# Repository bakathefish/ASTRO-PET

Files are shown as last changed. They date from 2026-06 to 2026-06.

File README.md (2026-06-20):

ZINE

# AstroPet

## What is it?
 
AstroPet is a small desk pet built for astrophotographers. It consists of two boards: a sensor unit that you leave outside exposed to the sky which reads actual sky conditions in real time, and a display unit that sits on your desk with a cute little animated pet face on a round screen.
 
The pet's mood tells you whether it's worth going outside to shoot tonight. A happy face means go, a sad face means stay in. No internet, no weather app, no phone needed so its ideal for when you're at a dark site in the middle of nowhere and just want a quick answer before dragging all your gear out into the cold.

## Why did i make it?

Everytime i want to go outside and shoot theres always the laziness preventing me. im always thinking what if its too bright, what if theres too many clouds, is the humidity right, is it time to go shoot yet or do i wait more. by the time iv figured it out all the motivation to shoot has faded, or the time to shoot has. so i figured if i have a small device pet telling me exactly what to do and if its a good idea to shoot, without me ever leaving the comfort of my bed, its perfect. i wanted something that would work anywhere regardless of if i had wifi.

right now im only doing the most basic things with the sensors, however overtime i plan to improve a lot on the design and firmware since this is just a v1 build of it. overtime i plan on adding more moods, maybe optional wifi modes that also pull planetary data and moon phase, and perhaps tell you what to shoot or an ideal setup to use. iv already ordered both pcbs and all the parts for them, so the plan now is to build them, test them properly irl and keep developing them out from there.

## how does it work

the two boards talk to eachother wirelessly over the esp32s esp now protocol, a direct device to device protocol that needs no router, no hotspot, or internet connection.

**board one** the sensor unit, it sits outside reading the data, the sensors fire every 5 seconds and the data is then transmitted over to board 2.
**board two** the display unit, it sits on your desk, receives the packets, runs three checks on the data and outputs a face to match all of it.

both boards just run off usb c for now since this is a v1.

## Why the ir temperature finds clouds
a clear sky would be a direct line of sight to space which would be cold, and the mlx90614 pointed upward would read that cold radiation and return a very very low temperature. however if it was pointed at a cloud the temperature would be much higher, and when we compare this with the surrounding temperature taken by the other sensor it allows us to predict if clouds are blocking the sky or not, without using any internet forecast data or camera since those will be unreliable in the dark.

## PCB 1 - Sensor Unit Schematic

SCH_sensor module_1-P1_2026-06-20

## PCB 1 - Sensor Unit Board


## PCB 2 - Display Unit Schematic


## PCB 2 - Display Unit Board


## 3d models / cases

the `3d models/` folder has the printable cases for both units, the desk display unit and the outdoor sensor unit. theres no screws anywhere in this whole build, both cases have clips on the inside that the pcb snaps into, and the lids clip shut over the top.

### display unit (indoor)

the round window is for the screen. you slide the pcb into the slot inside and it snaps into the clips, then the lid clips on over it.

<p align="center">
  display case front<br>
  <b>front</b>
</p>

<p align="center">
  display case back<br>
  <b>back</b>
</p>

<p align="center">
  display case view
</p>

### sensor unit (outdoor)

same setup, the pcb snaps into the clips inside and the lid clips closed over it. to actually put it outside you can just 3m double tape the bottom of the case onto a wall, a ledge or your roof, wherever it can see the open sky, so theres no drilling or screws needed for mounting it either.

<p align="center">
  sensor case front<br>
  <b>front</b>
</p>

<p align="center">
  sensor case back<br>
  <b>back</b>
</p>

## the firmware

the firmware is two little arduino sketches, `sensor_unit.ino` for the outside board and `display_unit.ino` for the desk board. i kept it super simple on purpose, theres barely any code so its easy to read and beginner friendly if you wanna build your own or mess around with it.

the sensor board just reads the three sensors and broadcasts them over esp now every 5 seconds. the display board listens, runs the three checks, and draws a happy or sad face. if it stops hearing from the sensor for a bit the pet goes to sleep so you know the link dropped.

right now theres **no gps and no moon phase** in the code, its the bare minimum to get the core thing working and keep it easy to flash. im adding gps + moon phase (and maybe an optional wifi mode) in a **v2** once iv built and tested the boards irl. the gps connector is already on the board so its just a firmware update later.

### flashing it
to flash, open the sketch in arduino ide, install the **esp32 by Espressif** board package and pick **ESP32S3 Dev Module** as the board, then plug the board in over usb c, select its com port and hit upload. install the libraries for whichever board youre flashing first:
- sensor board libraries: `Adafruit TSL2591`, `Adafruit MLX90614`, `Adafruit BME280`
- display board library: `TFT_eSPI`
- the round display needs `TFT_eSPI` set up for the **GC9A01** driver in its `User_Setup.h`, if the screen is black or garbled thats almost always why

## assembly

first step is getting the boards made, head to `PCB_FILES/` and download both gerber zips (`ASTROPET_SENSOR_PCB.zip` and `ASTROPET_DISPLAY_PCB.zip`), get them made at jlcpcb, and order the parts from the BOM below.

once the boards arrive, populate them by hand using the silkscreen markers as a guide. start with the smallest parts first like the resistors and caps, then move up to the bigger stuff like the esp32 modules and the connectors. everything on here is hand solderable so you dont need anything fancy, just a normal iron and a bit of flux.

after both boards are soldered, flash the firmware onto them. grab `sensor_unit.ino` and `display_unit.ino` from the `firmware/` folder and flash each one to its own board using the steps in the firmware section above. power for both is just usb c, so plug each board in over usb c to flash it and to run it.

then the cases, and remember theres no screws anywhere in this build.

for the display unit, connect the round screen to the board first and power it over usb c to check it actually works. once it does, unplug it, slide the pcb into the slot inside the case so it snaps into the clips, plug the screen back in, then clip the lid shut. thats it.

for the sensor unit its the same thing, the pcb snaps into the clips inside the case and the lid clips closed over it. to put it outside just 3m double tape the bottom of the case onto a wall, ledge or roof where it can see the sky.

once both are closed up, power them over usb c, keep the display unit on your desk and stick the sensor unit outside facing up at the open sky, and the pet should start reacting to whats going on up there.

## BOM

full bom with lcsc part numbers is in `BOM.csv`. order the pcbs from jlcpcb using the gerber files in `PCB_FILES/`.
 
| Qty | Description | Manufacturer | MPN | Supplier | Part No. | Unit (USD) | Total (USD) |
|-----|---|---|-----|---|---|---|---|
| 2 | [ESP32-S3-MINI-1-N4R2 module](https://www.lcsc.com/product-detail/C3013941.html?s_z=n_q_C3013941&globalKeyword=C3013941) | Espressif | ESP32-S3-MINI-1-N4R2 | LCSC | C3013941 | $5.15 | $10.31 |
| 2 | [RES 4.3kΩ 0603](https://www.lcsc.com/product-detail/C2930099.html?s_z=n_q_C2930099&globalKeyword=C2930099) | FOJAN | FRC0603F4301TS | LCSC | C2930099 | $0.002 | $0.003 |
| 7 | [CAP 100nF 0603](https://www.lcsc.com/product-detail/C14663.html?s_z=n_q_C14663&globalKeyword=C14663) | YAGEO | CC0603KRX7R9BB104 | LCSC | C14663 | $0.03 | $0.18 |
| 4 | [CAP 47µF 0805](https://www.lcsc.com/product-detail/C6119904.html?s_z=n_q_C6119904&globalKeyword=C6119904) | HRE | CGA0805X5R476M100MT | LCSC | C6119904 | $0.13 | $0.53 |
| 6 | [RES 10kΩ 0603](https://www.lcsc.com/product-detail/C2930027.html?s_z=n_q_C2930027&globalKeyword=C2930027) | FOJAN | FRC0603J103TS | LCSC | C2930027 | $0.001 | $0.008 |
| 4 | [Tactile button](https://www.lcsc.com/product-detail/C720477.html?s_z=n_q_C720477&globalKeyword=C720477) | XUNPU | TS-1088-AR02016 | LCSC | C720477 | $0.054 | $0.22 |
| 1 | [GPS connector JST 4-pin](https://www.lcsc.com/product-detail/C131334.html?s_z=n_q_C131334&globalKeyword=C131334) | JST | B4B-PH-K-S(LF)(SN) | LCSC | C131334 | $0.047 | $0.047 |
| 1 | [BME280 temp/humidity/pressure](https://www.lcsc.com/product-detail/C92489.html?s_z=n_q_C92489&globalKeyword=C92489) | Bosch | BME280 | LCSC | C92489 | $6.37 | $6.37 |
| 1 | [MLX90614ESF-BAA IR cloud sensor](https://www.lcsc.com/product-detail/C490604.html?s_z=n_q_C490604&globalKeyword=C490604) | Melexis | MLX90614ESF-BAA-000-TU | LCSC | C490604 | $6.56 | $6.56 |
| 1 | [TSL25911FN sky brightness sensor](https://www.lcsc.com/product-detail/C176812.html?s_z=n_q_C176812&globalKeyword=C176812) | AMS | TSL25911FN | LCSC | C176812 | $3.22 | $3.22 |
| 2 | [LED indicator](https://www.lcsc.com/product-detail/C5354976.html?s_z=n_q_C5354976&globalKeyword=C5354976) | Kingbright | APHHS1005LSECK/J3-PF | LCSC | C5354976 | $0.49 | $0.97 |
| 2 | [CAP 22µF](https://www.lcsc.com/product-detail/C5674.html?s_z=n_q_C5674&globalKeyword=C5674) | Samsung | CL21A226MQQNNNE | LCSC | C5674 | $0.039 | $0.078 |
| 2 | [LDO 3.3V AP2112K](https://www.lcsc.com/product-detail/C51118.html?s_z=n_q_C51118&globalKeyword=C51118) | Diodes Inc. | AP2112K-3.3TRG1 | LCSC | C51118 | $0.163 | $0.327 |
| 2 | [CAP 10µF](https://www.lcsc.com/product-detail/C15850.html?s_z=n_q_C15850&globalKeyword=C15850) | Samsung | CL21A106KAYNNNE | LCSC | C15850 | $0.048 | $0.095 |
| 4 | [RES 22Ω 0603](https://www.lcsc.com/product-detail/C23345.html?s_z=n_q_C23345&globalKeyword=C23345) | UNI-ROYAL | 0603WAF220JT5E | LCSC | C23345 | $0.002 | $0.006 |
| 2 | [ESD diode USBLC6-2SC6](https://www.lcsc.com/product-detail/C7519.html?s_z=n_q_C7519&globalKeyword=C7519) | ST | USBLC6-2SC6 | LCSC | C7519 | $0.154 | $0.308 |
| 2 | [Schottky diode MBR0520](https://www.lcsc.com/product-detail/C5204745.html?s_z=n_q_C5204745&globalKeyword=C5204745) | TWGMC | MBR0520 | LCSC | C5204745 | $0.021 | $0.042 |
| 2 | [Ferrite bead BLM18PG121SN1D](https://www.lcsc.com/product-detail/C14709.html?s_z=n_q_C14709&globalKeyword=C14709) | muRata | BLM18PG121SN1D | LCSC | C14709 | $0.017 | $0.034 |
| 2 | [PTC resettable fuse 75mA](https://www.lcsc.com/product-detail/C2830242.html?s_z=n_q_C2830242&globalKeyword=C2830242) | Jinrui | JK-nSMD075/6V | LCSC | C2830242 | $0.039 | $0.077 |
| 4 | [RES 5.1kΩ 0603](https://www.lcsc.com/product-detail/C2907044.html?s_z=n_q_C2907044&globalKeyword=C2907044) | FOJAN | FRC0603F5101TS | LCSC | C2907044 | $0.002 | $0.006 |
| 1 | [Display header 1x7 2.54mm](https://www.lcsc.com/product-detail/C22438157.html?s_z=n_q_C22438157&globalKeyword=C22438157) | Hanxia | HX PM2.54-1x7P ZC-Y | LCSC | C22438157 | $0.12 | $0.12 |
| 1 | [NEO-6M GPS module](https://robu.in/product/neo-6m-gps-module-with-eprom-normal-quality/) * | — | — | Robu.in | 1270231 | $3.00 | $3.00 |
| 1 | [GC9A01 1.28" round IPS display](https://robu.in/product/goldenmorning-gc9a01-7p-240x240-spi-1-28-inch-round-display-module/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) | — | — | Robu.in | R123209 | $4.00 | $4.00 |
| 2 | [2-layer PCB](https://cart.jlcpcb.com/quote?spm=jlcpcb.Public.2006) | — | — | JLCPCB | — | $2.10 | $4.20 |

**Total: ~$40.50 USD**

\* the neo-6m gps isnt used by the v1 firmware, its only on the board so gps + moon phase can be added later as a firmware update (see the firmware section). you can leave it unpopulated for now if you want.

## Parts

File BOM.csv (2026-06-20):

No. | Qty | Description | Manufacturer | MPN | Supplier | Part No. | Link | Unit (USD) | Total (USD) | Notes
1 | 2 | ESP32-S3-MINI-1-N4R2 module | Espressif | ESP32-S3-MINI-1-N4R2 | LCSC | C3013941 | https://www.lcsc.com/product-detail/C3013941.html?s_z=n_q_C3013941&globalKeyword=C3013941 | 5.15 | 10.31
2 | 2 | RES 4.3kΩ 0603 | FOJAN | FRC0603F4301TS | LCSC | C2930099 | https://www.lcsc.com/product-detail/C2930099.html?s_z=n_q_C2930099&globalKeyword=C2930099 | 0.002 | 0.003
3 | 7 | CAP 100nF 0603 | YAGEO | CC0603KRX7R9BB104 | LCSC | C14663 | https://www.lcsc.com/product-detail/C14663.html?s_z=n_q_C14663&globalKeyword=C14663 | 0.03 | 0.18
4 | 4 | CAP 47µF 0805 | HRE | CGA0805X5R476M100MT | LCSC | C6119904 | https://www.lcsc.com/product-detail/C6119904.html?s_z=n_q_C6119904&globalKeyword=C6119904 | 0.13 | 0.53
5 | 6 | RES 10kΩ 0603 | FOJAN | FRC0603J103TS | LCSC | C2930027 | https://www.lcsc.com/product-detail/C2930027.html?s_z=n_q_C2930027&globalKeyword=C2930027 | 0.001 | 0.008
6 | 4 | Tactile button | XUNPU | TS-1088-AR02016 | LCSC | C720477 | https://www.lcsc.com/product-detail/C720477.html?s_z=n_q_C720477&globalKeyword=C720477 | 0.054 | 0.22
7 | 1 | GPS connector JST 4-pin | JST | B4B-PH-K-S(LF)(SN) | LCSC | C131334 | https://www.lcsc.com/product-detail/C131334.html?s_z=n_q_C131334&globalKeyword=C131334 | 0.047 | 0.047
8 | 1 | BME280 temp/humidity/pressure | Bosch | BME280 | LCSC | C92489 | https://www.lcsc.com/product-detail/C92489.html?s_z=n_q_C92489&globalKeyword=C92489 | 6.37 | 6.37
9 | 1 | MLX90614ESF-BAA IR cloud sensor | Melexis | MLX90614ESF-BAA-000-TU | LCSC | C490604 | https://www.lcsc.com/product-detail/C490604.html?s_z=n_q_C490604&globalKeyword=C490604 | 6.56 | 6.56
10 | 1 | TSL25911FN sky brightness sensor | AMS | TSL25911FN | LCSC | C176812 | https://www.lcsc.com/product-detail/C176812.html?s_z=n_q_C176812&globalKeyword=C176812 | 3.22 | 3.22
11 | 2 | LED indicator | Kingbright | APHHS1005LSECK/J3-PF | LCSC | C5354976 | https://www.lcsc.com/product-detail/C5354976.html?s_z=n_q_C5354976&globalKeyword=C5354976 | 0.49 | 0.97
12 | 2 | CAP 22µF | Samsung | CL21A226MQQNNNE | LCSC | C5674 | https://www.lcsc.com/product-detail/C5674.html?s_z=n_q_C5674&globalKeyword=C5674 | 0.039 | 0.078
13 | 2 | LDO 3.3V AP2112K | Diodes Inc. | AP2112K-3.3TRG1 | LCSC | C51118 | https://www.lcsc.com/product-detail/C51118.html?s_z=n_q_C51118&globalKeyword=C51118 | 0.163 | 0.327
14 | 2 | CAP 10µF | Samsung | CL21A106KAYNNNE | LCSC | C15850 | https://www.lcsc.com/product-detail/C15850.html?s_z=n_q_C15850&globalKeyword=C15850 | 0.048 | 0.095
15 | 4 | RES 22Ω 0603 | UNI-ROYAL | 0603WAF220JT5E | LCSC | C23345 | https://www.lcsc.com/product-detail/C23345.html?s_z=n_q_C23345&globalKeyword=C23345 | 0.002 | 0.006
16 | 2 | ESD diode USBLC6-2SC6 | ST | USBLC6-2SC6 | LCSC | C7519 | https://www.lcsc.com/product-detail/C7519.html?s_z=n_q_C7519&globalKeyword=C7519 | 0.154 | 0.308
17 | 2 | Schottky diode MBR0520 | TWGMC | MBR0520 | LCSC | C5204745 | https://www.lcsc.com/product-detail/C5204745.html?s_z=n_q_C5204745&globalKeyword=C5204745 | 0.021 | 0.042
18 | 2 | Ferrite bead BLM18PG121SN1D | muRata | BLM18PG121SN1D | LCSC | C14709 | https://www.lcsc.com/product-detail/C14709.html?s_z=n_q_C14709&globalKeyword=C14709 | 0.017 | 0.034
19 | 2 | PTC resettable fuse 75mA | Jinrui | JK-nSMD075/6V | LCSC | C2830242 | https://www.lcsc.com/product-detail/C2830242.html?s_z=n_q_C2830242&globalKeyword=C2830242 | 0.039 | 0.077
20 | 4 | RES 5.1kΩ 0603 | FOJAN | FRC0603F5101TS | LCSC | C2907044 | https://www.lcsc.com/product-detail/C2907044.html?s_z=n_q_C2907044&globalKeyword=C2907044 | 0.002 | 0.006
21 | 1 | Display header 1x7 2.54mm | Hanxia | HX PM2.54-1x7P ZC-Y | LCSC | C22438157 | https://www.lcsc.com/product-detail/C22438157.html?s_z=n_q_C22438157&globalKeyword=C22438157 | 0.12 | 0.12
22 | 1 | NEO-6M GPS module |  |  | Robu.in | 1270231 | https://robu.in/product/neo-6m-gps-module-with-eprom-normal-quality/ | 3 | 3 | not used by v1 firmware, optional, can leave unpopulated
23 | 1 | GC9A01 1.28" round IPS display |  |  | Robu.in | R123209 | https://robu.in/product/goldenmorning-gc9a01-7p-240x240-spi-1-28-inch-round-display-module/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 | 4 | 4
24 | 2 | 2-layer PCB |  |  | JLCPCB |  | https://cart.jlcpcb.com/quote?spm=jlcpcb.Public.2006 | 2.1 | 4.2
 |  |  |  |  |  |  |  | TOTAL (USD) | 40.71

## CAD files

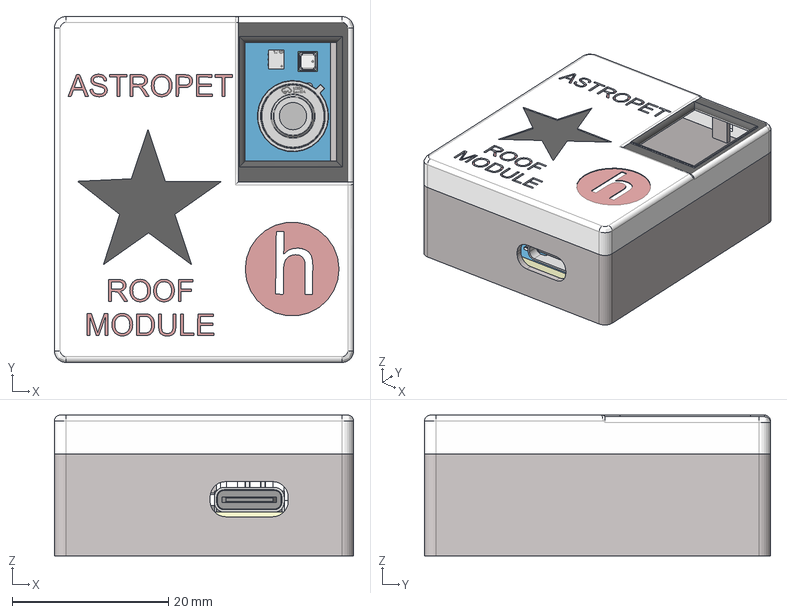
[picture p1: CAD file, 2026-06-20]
3d models/ASTROPET_ROOF.step
38.3 x 44.3 x 18.0 mm
Board~mEyu
SW-SMD_L3.9-W3.0-P4.45~SW-SMD_L3.9-W2.9-H2.0-LS4.8~L6eX x 2
C0805~C0805_L2.0-W1.3-H1.3~uovY x 4
C0603~C0603_L1.6-W0.8-H0.8~0AP0 x 5
TO-39-4_MELEXIS_MLX90614XXA~TO-39-4_MELEXIS_MLX90614XXA~DdZP
F1206~F1206_L3.2-W1.7-H0.6~eitb
L0603~L0603_L1.6-W0.8-H0.5_BEAD~ujBa
SOT-23-6_L2.9-W1.6-P0.95-LS2.8-BL~SOT-23-6_L2.9-W1.6-H1.5-LS2.8-P0.95 ~Gd1i
LED0402-RD_RED~LED0402-RD_RED~1LAU
R0603~R0603~h1d3 x 9
SOD-123_L2.7-W1.6-LS3.7-RD-A~SOD-123_L2.7-W1.6-LS3.7-RD-A~o5sd
BULETM-SMD_ESP32-S3-MINI-1-N8~BULETM-SMD_ESP32-S3-MINI-1-N8~e1Fh
USB-C-SMD_TYPEC-304J-BCP16~USB-C-SMD_TYPEC-304J-BCP16~HAKh
SOT-25-5_L2.9-W1.6-P0.95-LS2.8-BL~SOT-25-5_L2.9-W1.6-P0.95-LS2.8-BL~4 HVq
LGA-8_BME280_BL~LGA-8_L2.5-W2.5-H0.9-P0.65~OiZE
DFN-6_L2.4-W2.0-P0.65-BL~DFN-6_L2.4-W2.0-P0.65-BL~LcKs
CONN-TH_B4B-PH-K-S~PH2.0-LI-4P~i7Em

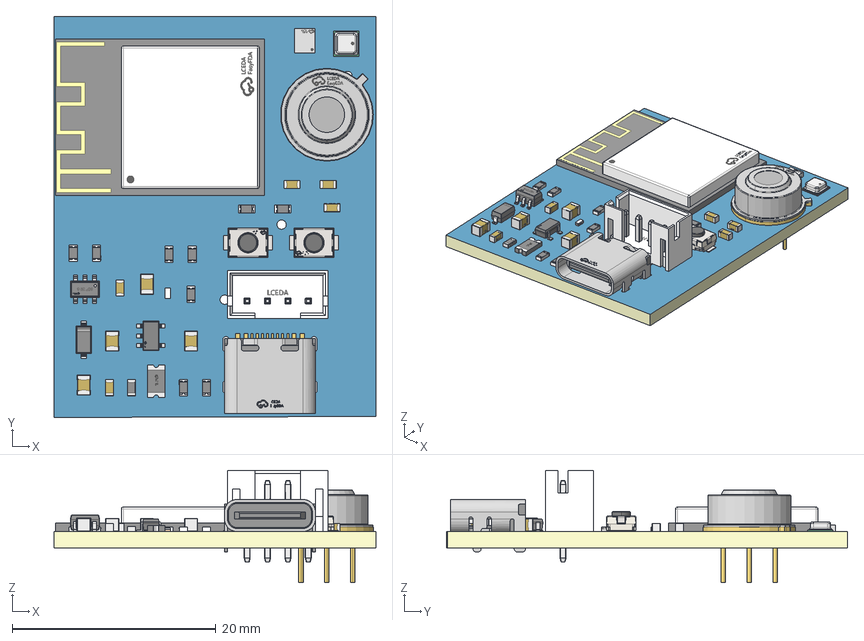
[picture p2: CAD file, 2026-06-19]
PCB_FILES/ASTROPET_SENSOR_3d.step
31.6 x 39.4 x 11.0 mm
Board~7xb7
TopCopper~7xb7
BottomCopper~7xb7
TopFpcStiffener~7xb7
BottomFpcStiffener~7xb7
C0603~C0603_L1.6-W0.8-H0.8~7xb7 x 5
C0805~C0805_L2.0-W1.3-H1.3~7xb7 x 4
F1206~F1206_L3.2-W1.7-H0.6~7xb7
L0603~L0603_L1.6-W0.8-H0.5_BEAD~7xb7
SW-SMD_L3.9-W3.0-P4.45~SW-SMD_L3.9-W2.9-H2.0-LS4.8~7xb7 x 2
R0603~R0603~7xb7 x 9
LED0402-RD_RED~LED0402-RD_RED~7xb7
SOT-23-6_L2.9-W1.6-P0.95-LS2.8-BL~SOT-23-6_ L2.9-W1.6-H1.5-LS2.8-P0.95~7xb7
SOD-123_L2.7-W1.6-LS3.7-RD-A~SOD-123_L2.7-W1.6-LS3.7-RD-A~7xb7
BULETM-SMD_ESP32-S3-MINI-1-N8~BULETM-SMD_ESP32-S3-MINI-1-N8~7xb7
SOT-25-5_L2.9-W1.6-P0.95-LS2.8-BL~SOT-25-5_ L2.9-W1.6-P0.95-LS2.8-BL~7xb7
USB-C-SMD_TYPEC-304J-BCP16~USB-C-SMD_TYPEC-304J-BCP16~7xb7
TO-39-4_MELEXIS_MLX90614XXA~TO-39-4_MELEXIS_MLX90614XXA~7xb7
DFN-6_L2.4-W2.0-P0.65-BL~DFN-6_L2.4-W2.0-P0.65-BL~7xb7
LGA-8_BME280_BL~LGA-8_L2.5-W2.5-H0.9-P0.65~7xb7
CONN-TH_B4B-PH-K-S~PH2.0-LI-4P~7xb7

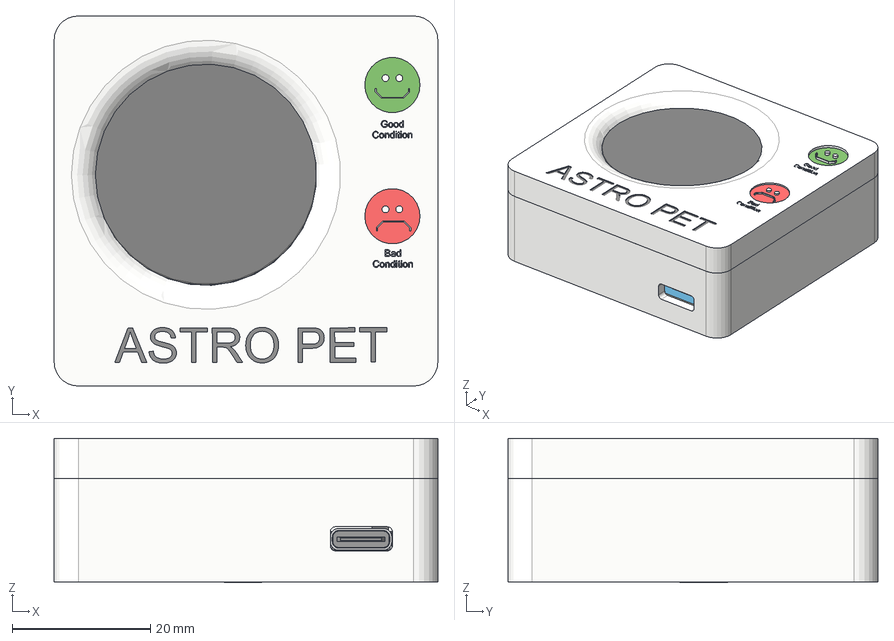
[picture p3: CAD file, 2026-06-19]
3d models/ASTROPET_SCREEN_STEP.step
55.6 x 53.6 x 20.9 mm
Board~KlHw
TopSilkscreen~KlHw_1
TopSilkscreen~KlHw_2
TopSilkscreen~KlHw_3
TopSilkscreen~KlHw_4
TopSilkscreen~KlHw_5
TopSilkscreen~KlHw_6
TopSilkscreen~KlHw_7
TopSilkscreen~KlHw_8
TopSilkscreen~KlHw_9
TopSilkscreen~KlHw_10
TopSilkscreen~KlHw_11
TopSilkscreen~KlHw_12
TopSilkscreen~KlHw_13
TopSilkscreen~KlHw_14
TopSilkscreen~KlHw_15
TopSilkscreen~KlHw_16
TopSilkscreen~KlHw_17
TopSilkscreen~KlHw_18
TopSilkscreen~KlHw_19
TopSilkscreen~KlHw_20
TopSilkscreen~KlHw_21
TopSilkscreen~KlHw_22
TopSilkscreen~KlHw_23
TopSilkscreen~KlHw_24
TopSilkscreen~KlHw_25
TopSilkscreen~KlHw_26
TopSilkscreen~KlHw_27
TopSilkscreen~KlHw_28
TopSilkscreen~KlHw_29
TopSilkscreen~KlHw_30
TopSilkscreen~KlHw_31
TopSilkscreen~KlHw_32
TopSilkscreen~KlHw_33
TopSilkscreen~KlHw_34
TopSilkscreen~KlHw_35
TopSilkscreen~KlHw_36
TopSilkscreen~KlHw_37
TopSilkscreen~KlHw_38
TopSilkscreen~KlHw_39
TopSilkscreen~KlHw_40
TopSilkscreen~KlHw_41
TopSilkscreen~KlHw_42
TopSilkscreen~KlHw_43
TopSilkscreen~KlHw_44
TopSilkscreen~KlHw_45
TopSilkscreen~KlHw_46
TopSilkscreen~KlHw_47
TopSilkscreen~KlHw_48
TopSilkscreen~KlHw_49
TopSilkscreen~KlHw_50
TopSilkscreen~KlHw_51
TopSilkscreen~KlHw_52
TopSilkscreen~KlHw_53
TopSilkscreen~KlHw_54
TopSilkscreen~KlHw_55
TopSilkscreen~KlHw_56
TopSilkscreen~KlHw_57
TopSilkscreen~KlHw_58
TopSilkscreen~KlHw_59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

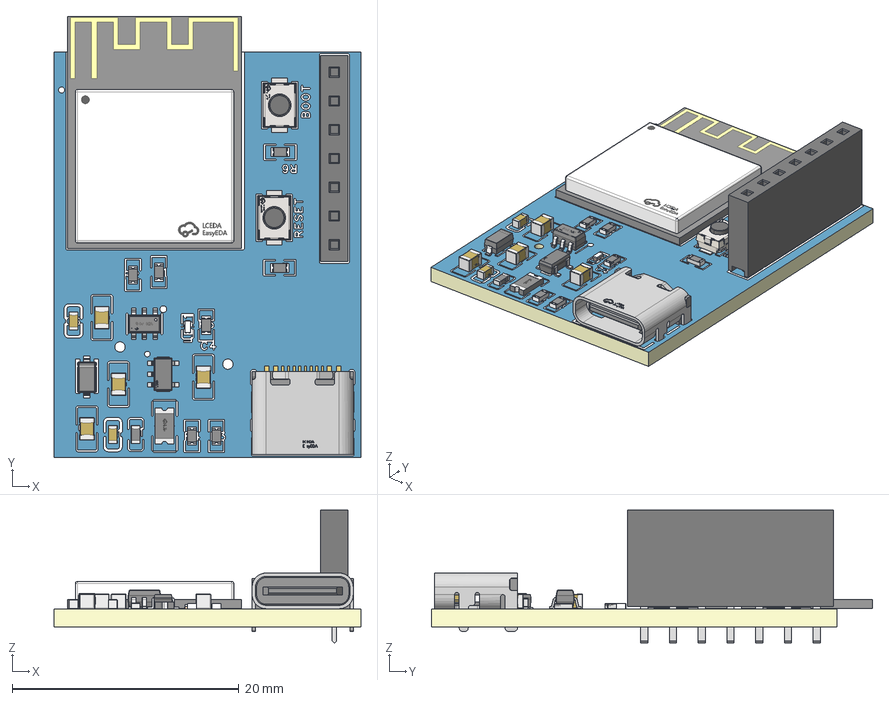
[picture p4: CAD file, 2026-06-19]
PCB_FILES/ASTROPET_DISPLAY_3d.step
27.1 x 38.9 x 11.7 mm
Board~jRkk
TopCopper~jRkk
BottomCopper~jRkk
TopSilkscreen~jRkk
TopFpcStiffener~jRkk
BottomFpcStiffener~jRkk
SW-SMD_L3.9-W3.0-P4.45~SW-SMD_L3.9-W2.9-H2.0-LS4.8~jRkk x 2
HDR-TH_7P-P2.54-V-F~HDR-TH_7P-P2.54-F-LI-1X7P~jRkk
R0603~R0603~jRkk x 7
C0805~C0805_L2.0-W1.3-H1.3~jRkk x 4
C0603~C0603_L1.6-W0.8-H0.8~jRkk x 2
L0603~L0603_L1.6-W0.8-H0.5_BEAD~jRkk
LED0402-RD_RED~LED0402-RD_RED~jRkk
SOD-123_L2.7-W1.6-LS3.7-RD-A~SOD-123_L2.7-W1.6-LS3.7-RD-A~jRkk
USB-C-SMD_TYPEC-304J-BCP16~USB-C-SMD_TYPEC-304J-BCP16~jRkk
BULETM-SMD_ESP32-S3-MINI-1-N8~BULETM-SMD_ESP32-S3-MINI-1-N8~jRkk
SOT-25-5_L2.9-W1.6-P0.95-LS2.8-BL~SOT-25-5_ L2.9-W1.6-P0.95-LS2.8-BL~jRkk
F1206~F1206_L3.2-W1.7-H0.6~jRkk
SOT-23-6_L2.9-W1.6-P0.95-LS2.8-BL~SOT-23-6_ L2.9-W1.6-H1.5-LS2.8-P0.95~jRkk

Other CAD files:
3d models/ASTROPET_ROOF.f3z
3d models/ASTROPET_SCREEN_F3D.f3z

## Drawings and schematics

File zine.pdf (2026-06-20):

# ASTRO PET

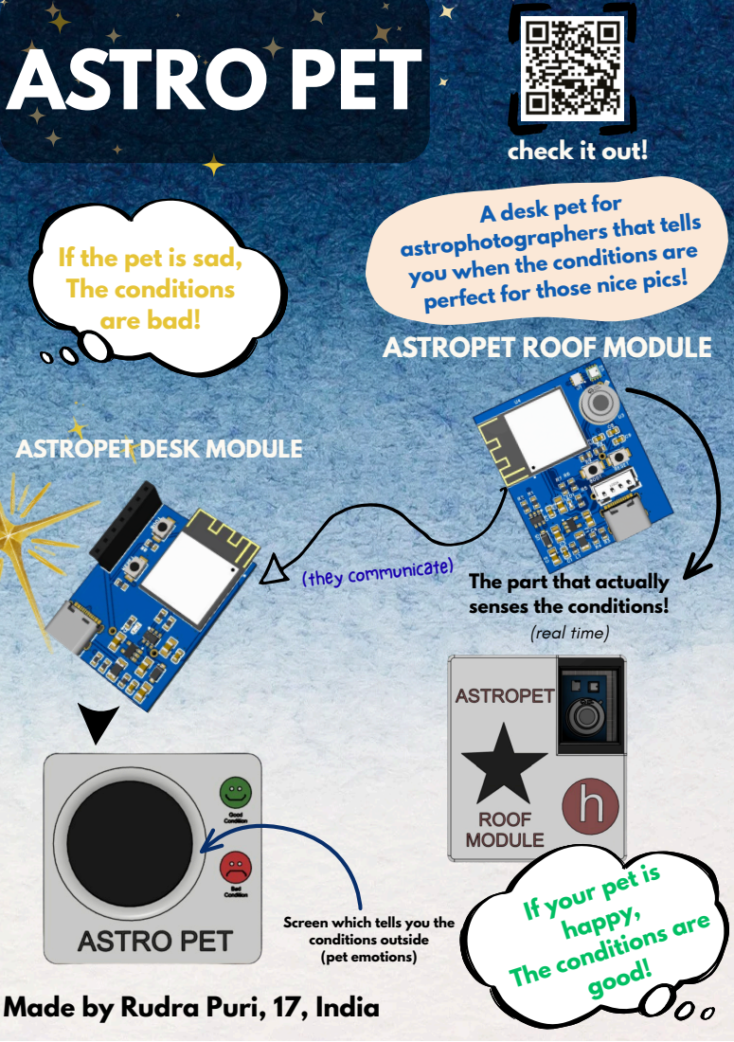
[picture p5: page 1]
(real time); happy,; good!; (they communicate)

check it out!

A desk pet for

astrophotographers that tells

you when the conditions are

If the pet is sad,
The conditions
are bad!

perfect for those nice pics!

ASTROPET ROOF MODULE

ASTROPET DESK MODULE

The part that actually
senses the conditions!

If your pet is

Screen which tells you the
conditions outside
(pet emotions)

The conditions are

Made by Rudra Puri, 17, India

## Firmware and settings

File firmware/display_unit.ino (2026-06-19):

// AstroPet display unit: draws a pet face from the sensor data
// TFT_eSPI must be set to the GC9A01 driver in its User_Setup.h or the screen stays black
#include <TFT_eSPI.h>
#include <esp_now.h>
#include <WiFi.h>

struct Data { float lux, skyTemp, airTemp, humidity; } d;
TFT_eSPI tft = TFT_eSPI();
volatile bool fresh = false;
volatile unsigned long lastRecv = 0;
int last = -1;                       // -1 none, 0 sad, 1 happy, 2 asleep

void onRecv(const esp_now_recv_info_t *i, const uint8_t *data, int len) {
  if (len == sizeof(d)) { memcpy(&d, data, len); fresh = true; lastRecv = millis(); }
}

void draw(int mood) {                // 0 sad, 1 happy, 2 asleep
  tft.fillScreen(TFT_BLACK);
  tft.fillCircle(120, 110, 70, TFT_YELLOW);
  if (mood == 2) {                   // closed eyes
    tft.fillRect(85, 88, 22, 4, TFT_BLACK);
    tft.fillRect(133, 88, 22, 4, TFT_BLACK);
  } else {                           // open eyes
    tft.fillCircle(95, 90, 8, TFT_BLACK);
    tft.fillCircle(145, 90, 8, TFT_BLACK);
  }
  for (int x = -30; x <= 30; x++) {  // mouth: smile / frown / flat
    int y = mood == 1 ? 158-(x*x)/35 : mood == 0 ? 142+(x*x)/35 : 138;
    tft.fillCircle(120 + x, y, 3, TFT_BLACK);
  }
  tft.setTextColor(TFT_WHITE); tft.setTextSize(2);
  tft.setCursor(mood == 1 ? 66 : mood == 2 ? 60 : 54, 200);
  tft.print(mood == 1 ? "Go shoot!" : mood == 2 ? "No signal" : "Stay inside");
}

void setup() {
  tft.init(); tft.setRotation(0); tft.fillScreen(TFT_BLACK);
  WiFi.mode(WIFI_STA);
  esp_now_init();
  esp_now_register_recv_cb(onRecv);
}

void loop() {
  if (lastRecv && millis() - lastRecv > 15000) {   // no packets for 15s -> sleep
    if (last != 2) { last = 2; draw(2); }
    return;
  }
  if (!fresh) return;
  fresh = false;
  // 3 checks: dark enough, clear sky (cold sky), low humidity
  int score = (d.lux >= 0 && d.lux < 10) + (d.airTemp - d.skyTemp > 10) + (d.humidity < 70);
  int mood = score >= 2;             // happy if 2 of 3 pass
  if (mood != last) { last = mood; draw(mood); }
}

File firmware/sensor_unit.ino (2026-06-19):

// AstroPet sensor unit: reads the sky and broadcasts over ESP-NOW every 5s
#include <Wire.h>
#include <Adafruit_TSL2591.h>
#include <Adafruit_MLX90614.h>
#include <Adafruit_BME280.h>
#include <esp_now.h>
#include <WiFi.h>

struct Data { float lux, skyTemp, airTemp, humidity; } d;
uint8_t peer[] = {0xFF,0xFF,0xFF,0xFF,0xFF,0xFF};

Adafruit_TSL2591 tsl = Adafruit_TSL2591(2591);
Adafruit_MLX90614 mlx;
Adafruit_BME280 bme;
unsigned long last = 0;

void setup() {
  Wire.begin(8, 9);                 // SDA 8, SCL 9
  tsl.begin(); mlx.begin(); bme.begin(0x76);   // try 0x77 if bme not found
  tsl.setGain(TSL2591_GAIN_HIGH);              // more sensitive in the dark
  tsl.setTiming(TSL2591_INTEGRATIONTIME_300MS);

  WiFi.mode(WIFI_STA);
  esp_now_init();
  esp_now_peer_info_t p = {};
  memcpy(p.peer_addr, peer, 6);
  esp_now_add_peer(&p);
}

void loop() {
  if (millis() - last < 5000) return;
  last = millis();
  sensors_event_t e; tsl.getEvent(&e);
  d.lux = e.light;
  d.skyTemp = mlx.readObjectTempC();
  d.airTemp = mlx.readAmbientTempC();
  d.humidity = bme.readHumidity();
  esp_now_send(peer, (uint8_t*)&d, sizeof(d));
}

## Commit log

2026-06-19 Initial commit: ASTRO PET hardware project
    Firmware, PCB files, 3D models, and BOM.
    [ASTROPET_DISPLAY_3d.step, ASTROPET_ROOF.f3z, ASTROPET_ROOF.step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]
2026-06-20 Update 3D models
    [ASTROPET_ROOF.f3z, ASTROPET_ROOF.step]
2026-06-20 Remove old 3D models
    [ASTROPET_ROOF.f3z, ASTROPET_ROOF.step]
2026-06-20 Add updated 3D models
    [ASTROPET_ROOF.f3z, ASTROPET_ROOF.step]
2026-06-20 Add screen 3D models
    [ASTROPET_SCREEN_F3D.f3z, ASTROPET_SCREEN_STEP.step]
